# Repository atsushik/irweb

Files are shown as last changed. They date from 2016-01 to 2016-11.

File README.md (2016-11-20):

# irweb
irkitもどきを安く作るための何か

## 目的

家電を多少なりとも制御しようと思うと、既存の家電を操作するための手段が極めて限られている現実に直面する。

エアコンやテレビ、電灯などは赤外線を用いたリモコンによる操作が可能だが、WEB API的に操作できるとさらに捗りそうな気がする。

用途は例えば↓下記など。

- 寒い冬の明け方にベッドの中から他の部屋にあるエアコンの暖房をONにしたい
- 暑い夏の日に外から帰る前に室内を適温に冷やしておきたい
- 人感センサなどと組み合わせて電灯をON/OFFしたい

なお、学習リモコンは「送信できる信号は、過去に受信して記憶させたもののみ」という面で機能的に不足していると思っている。

このため、「室温が１８度になったら記憶させた温度で暖房をつける」はできるが、それ以上の細かい制御は（不可能ではないが）面倒くさいのでやらなくなる(が、多分、実用性という点ではそれで十分なのだとも思う)。

どうせなら任意の信号を出せる方が面白いと思うので簡単な変換スクリプトも作った。

## 材料
- [ESP8266なWIFIモジュール](http://akizukidenshi.com/catalog/g/gK-09758/) とARDUINOとして使うための一式
- [５ｍｍ赤外線ＬＥＤ　ＯＳＩ５ＬＡ５１１３Ａ　（１０個入）](http://akizukidenshi.com/catalog/g/gI-04311/)
- [赤外線リモコン受信モジュール　ＧＰ１ＵＸＣ４１ＱＳ](http://akizukidenshi.com/catalog/g/gI-06487/)
- [角型２色ＬＥＤ　赤・黄緑　ＧＬ８ＥＤ４８　（１０個)](http://akizukidenshi.com/catalog/g/gI-03255/)

## 配線
NODEMCUの絵を使っているけど、WROOMに適宜読み替える
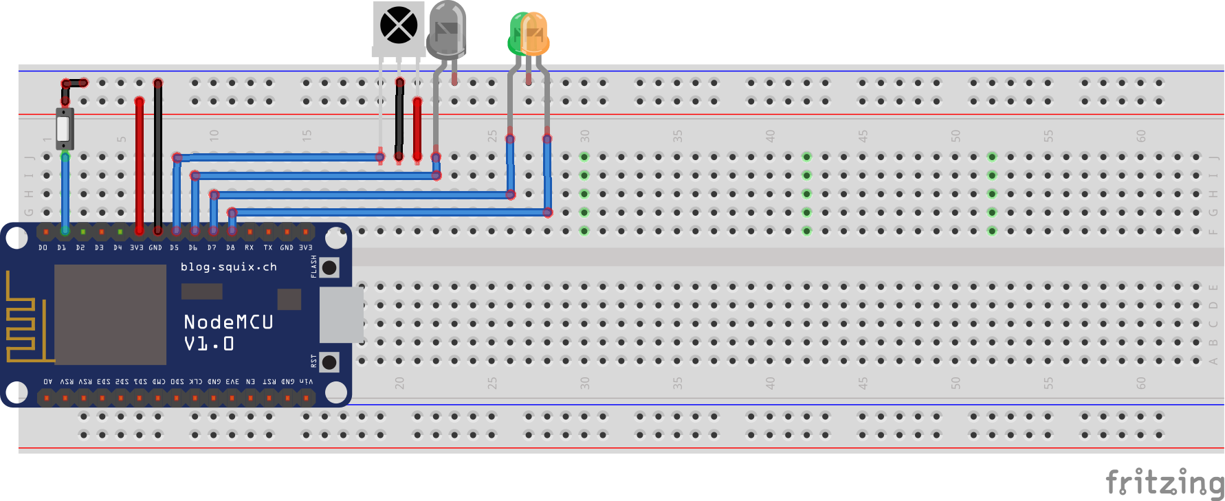
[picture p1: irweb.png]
配線図


| NODEMCU| GPIO|つなぐもの |
|:---:|:---:|:---:|
| D4 | 2 | |
| D1 | 5 | |
| D6 |  12 |５ｍｍ赤外線ＬＥＤ |
| D7 |  13 |角型２色ＬＥＤ　赤・黄緑 緑側| 
| D5 |  14 |赤外線リモコン受信モジュール |
| D8 |  15 |角型２色ＬＥＤ　赤・黄緑 赤側|
| D0 |  16 | |

## 依存しているライブラリ
- [tzapu/WiFiManager](https://github.com/tzapu/WiFiManager)
- [markszabo/IRremoteESP8266](https://github.com/markszabo/IRremoteESP8266)
- [bblanchon/ArduinoJson](https://github.com/bblanchon/ArduinoJson)

## 使い方

### 初回起動時
「irweb_c1a1」みたいなWIFI-APが出現するので、そこにつなぐ。
少し待つと「Configure WiFi」と書かれたボタンが出るので、クリックして、表示されるAP一覧から接続したいのを選びパスワードを入力する。
次回起動時からはその情報を使ってWIFIに接続するようになる。
AP情報を消すにはWIFIモジュールの起動時に GPIO 5 をGNDに繋いでおくと、保存していた情報を消す。

### esp8266の探し方
ホスト名は「irweb_」+「MACアドレスの下４文字」になっている

- osxならdns-sd コマンドで _irweb._tcp を探すとホスト名がわかる。
``` sh:find_irweb.sh
$ dns-sd -B _irweb._tcp
Browsing for _irweb._tcp
DATE: ---Sun 31 Jan 2016---
 2:21:45.561  ...STARTING...
Timestamp     A/R    Flags  if Domain               Service Type         Instance Name
 2:21:46.040  Add        2   5 local.               _irweb._tcp.         irweb_c1a1
```

- linuxならavahi-browse コマンドで _irweb._tcp を探すとホスト名がわかる。
``` sh:find_irweb.sh
$ avahi-browse _irweb._tcp
+   eth0 IPv4 irweb_c1a1                                    _irweb._tcp          local
```

### 受信
受信したリモコンの信号は下記のURLにアクセスするとjson形式で取得できる

URLのc1a1の部分は適宜変更する

http://irweb_c1a1.local/messages
``` json:aquos_power.json
{"format":"raw","freq":38,"len":99,"data":[3400,1700,450,450,450,1250,450,450,450,1250,450,450,450,1250,450,450,450,1250,450,450,450,1250,450,450,450,1250,450,1250,450,450,450,1250,450,450,450,1250,450,1250,450,1250,450,1250,450,450,450,450,450,450,450,1250,450,450,450,1250,450,450,450,450,450,1250,450,450,450,450,450,450,450,450,450,1250,450,1250,450,450,450,1250,450,450,450,450,450,450,450,1250,450,450,450,450,450,450,450,1250,450,450,450,1250,450,1250,450]}
```

### 送信
上記で取得したjsonをPOSTするとそれに応じてリモコン信号を送信する

URLのc1a1の部分は適宜変更する

``` sh:sendIrSignal.sh
curl -i "http://irweb_c1a1.local/messages" -H "X-Requested-With: curl" --data-binary @/irweb/data/sharp/ac-222fd/warm20_Louver2.json
```

### おまけ１
同梱の irweb2bin.py を使うと赤外線のON/OFFを1/0のバイナリに変換できる。
いくつかパターンを集めると、例えばエアコンの温度がどこに格納されているのかがわかるようになる。
``` sh:decodeIr.sh
$ cat /irweb/data/sharp/ac-222fd/warm20_Louver2.json | python /irweb/irweb2bin.py
AEHA	01010101010110101111001100001000110000001000100010000100000000000101000000000101000000000010011110000110
```

下記が必要
```
cpan install JSON
```

### おまけ２
同梱の bin2irweb.py を使うと1/0のバイナリを赤外線のON/OFFに変換できる。
任意の温度を設定した赤外線リモコン信号を送ることができるようになる。
``` sh:encodeIr.sh
$ echo "AEHA	01010101010110101111001100001000110000001000100010000100000000000101000000000101000000000010011110000110" | python /irweb/bin2irweb.py 
{"freq": 38, "data": [3400, 1700, 425, 425, 425, 1275, 425, 425, 425, 1275, 425, 425, 425, 1275, 425, 425, 425, 1275, 425, 425, 425, 1275, 425, 425, 425, 1275, 425, 1275, 425, 425, 425, 1275, 425, 425, 425, 1275, 425, 1275, 425, 1275, 425, 1275, 425, 425, 425, 425, 425, 1275, 425, 1275, 425, 425, 425, 425, 425, 425, 425, 425, 425, 1275, 425, 425, 425, 425, 425, 425, 425, 1275, 425, 1275, 425, 425, 425, 425, 425, 425, 425, 425, 425, 425, 425, 425, 425, 1275, 425, 425, 425, 425, 425, 425, 425, 1275, 425, 425, 425, 425, 425, 425, 425, 1275, 425, 425, 425, 425, 425, 425, 425, 425, 425, 1275, 425, 425, 425, 425, 425, 425, 425, 425, 425, 425, 425, 425, 425, 425, 425, 425, 425, 425, 425, 425, 425, 425, 425, 1275, 425, 425, 425, 1275, 425, 425, 425, 425, 425, 425, 425, 425, 425, 425, 425, 425, 425, 425, 425, 425, 425, 425, 425, 1275, 425, 425, 425, 1275, 425, 425, 425, 425, 425, 425, 425, 425, 425, 425, 425, 425, 425, 425, 425, 425, 425, 425, 425, 425, 425, 1275, 425, 425, 425, 425, 425, 1275, 425, 1275, 425, 1275, 425, 1275, 425, 425, 425, 425, 425, 425, 425, 425, 425, 1275, 425, 1275, 425, 425, 425], "len": 211, "format": "raw"}
```

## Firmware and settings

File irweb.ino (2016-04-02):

#include <ESP8266WiFi.h>          // https://github.com/esp8266/Arduino
//needed for library
#include <DNSServer.h>
#include <ESP8266WebServer.h>
#include <WiFiManager.h>          // https://github.com/tzapu/WiFiManager
//
#include <IRremoteESP8266.h>      // https://github.com/markszabo/IRremoteESP8266
//
#include <ESP8266mDNS.h>
//
//#include <ArduinoJson.h>          // https://github.com/bblanchon/ArduinoJson

// pin  0 is D3  on nodemcu
// pin  1 is D10 on nodemcu
// pin  2 is D4  on nodemcu
// pin  3 is D9  on nodemcu
// pin  4 is D2  on nodemcu
// pin  5 is D1  on nodemcu
// pin 12 is D6  on nodemcu
// pin 13 is D7  on nodemcu
// pin 14 is D5  on nodemcu
// pin 15 is D8  on nodemcu
// pin 16 is D0  on nodemcu

int RESET_AP_SETTING_PIN = 5;
int LED_RED  = 15;
int LED_GRN  = 13;
int RECV_PIN = 14;

IRrecv irrecv(RECV_PIN);
IRsend irsend(12);
decode_results  results;        // Somewhere to store the results

unsigned int irBufSize = 300;
unsigned int irBuf[300];

String jsonStr;

//String myName = "esp8266";
String myName = "irweb";

ESP8266WebServer webserver ( 80 );

byte mac[6];
char szMac[18];

void blink()
{
  for (int i = 0 ; i < 2; i++) {
    digitalWrite(LED_GRN, LOW);
    delay(60);
    digitalWrite(LED_GRN, HIGH);
    delay(60);
  }
}

void handleRoot() {
  blink();
  char temp[2048];
  int sec = millis() / 1000;
  int min = sec / 60;
  int hr = min / 60;

  snprintf ( temp, 2048,

             "<html>\
  <head>\
    <meta http-equiv='refresh' content='5'/>\
    <title>ESP8266 Demo</title>\
    <style>\
      body { background-color: #cccccc; font-family: Arial, Helvetica, Sans-Serif; Color: #000088; }\
    </style>\
  </head>\
  <body>\
    <h1>%s</h1>\
    <p>Uptime: %02d:%02d:%02d</p>\
    <p>ir-signal: %s</p>\
    <img src=\"/test.svg\" />\
    <br>\
    <pre></pre>\
  </body>\
</html>",
             myName.c_str(), hr, min % 60, sec % 60, jsonStr.c_str()
           );
  webserver.send ( 200, "text/html", temp );
}

void handleMessages() {
  Serial.print("handleMessage : begin  at ");
  Serial.println(millis());
  blink();
  if ( webserver.method() == HTTP_GET ) {
    webserver.send ( 200, "application/json", jsonStr );
    jsonStr = String("");
  }
  else if ( webserver.method() == HTTP_POST ) {
    Serial.println("POST recieved");
    for (int i = 0; i < webserver.args(); i++) {
      String s = String(webserver.argName(i));
      s += String(" -> ");
      s += String(webserver.arg(i));
      if (String(webserver.argName(i)) == String("plain")) {
        jsonStr = String(webserver.arg(i));
      }
    }
    Serial.println(jsonStr);

    unsigned int fromIdx  = jsonStr.indexOf("\"data\":", 0) + 7;
    unsigned int fromIdx2 = jsonStr.indexOf("[", fromIdx) + 1;
    unsigned int toIdx    = jsonStr.indexOf("]", fromIdx2);
    String sigStr = jsonStr.substring(fromIdx2, toIdx);
    Serial.print("data : ");
    Serial.println(sigStr);

    fromIdx = 0;
    toIdx = 0;
    unsigned int sigIdx = 0;
    while (sigStr.length() > 0) {
      toIdx = fromIdx;
      while (toIdx < sigStr.length() && sigStr.charAt(toIdx) != ',') {
        toIdx ++;
      }
      String buf = sigStr.substring(fromIdx, toIdx);
      buf.trim();
      irBuf[sigIdx] = buf.toInt();
      sigStr = sigStr.substring(toIdx+1, sigStr.length());
      sigIdx++;
    }
    irBuf[sigIdx] = sigStr.substring(fromIdx, sigStr.length()).toInt();
    irsend.sendRaw(irBuf, sigIdx, 38);
    webserver.send ( 200, "text/plain", "" );
  }
  Serial.print("handleMessage : finish at ");
  Serial.println(millis());

}

void setup() {
  // put your setup code here, to run once:
  Serial.begin(115200);
  //Serial.begin(230400);

  pinMode(RESET_AP_SETTING_PIN, INPUT_PULLUP);

  pinMode(LED_RED, OUTPUT);
  pinMode(LED_GRN, OUTPUT);

  digitalWrite(LED_RED, HIGH);
  digitalWrite(LED_GRN, HIGH);

  WiFi.macAddress(mac);
  //sprintf(szMac, "%02x:%02x:%02x:%02x:%02x:%02x", mac[0], mac[1], mac[2], mac[3], mac[4], mac[5]);
  //sprintf(szMac, "%02x%02x%02x%02x%02x%02x", mac[0], mac[1], mac[2], mac[3], mac[4], mac[5]);
  sprintf(szMac, "%02x%02x", mac[4], mac[5]);
  myName += String("_");
  myName += String(szMac);

  //WiFiManager
  //Local intialization. Once its business is done, there is no need to keep it around
  WiFiManager wifiManager;
  Serial.print("GPIO 16 is ");
  Serial.print(digitalRead(RESET_AP_SETTING_PIN));
  //reset settings
  // 電源投入時に GPIO5 がLOWならばWIFIの設定を削除する
  if ( digitalRead(RESET_AP_SETTING_PIN) == 0 ) {
    wifiManager.resetSettings();
  }

  //sets timeout until configuration portal gets turned off
  //useful to make it all retry or go to sleep
  //in seconds
  wifiManager.setTimeout(180);

  //fetches ssid and pass and tries to connect
  //if it does not connect it starts an access point with the specified name
  //here  "esp8266-" followed by MAC Address
  //and goes into a blocking loop awaiting configuration
  if (!wifiManager.autoConnect(myName.c_str())) {
    digitalWrite(LED_RED, HIGH);
    digitalWrite(LED_GRN, LOW);

    Serial.println("failed to connect and hit timeout");
    delay(3000);
    //reset and try again, or maybe put it to deep sleep
    ESP.reset();
    delay(5000);
  }

  //if you get here you have connected to the WiFi
  Serial.println("connected...yeey :)");
  digitalWrite(LED_RED, LOW);
  digitalWrite(LED_GRN, HIGH);

  irrecv.enableIRIn();  // Start the receiver
  irsend.begin();
  if ( MDNS.begin ( myName.c_str() , WiFi.localIP(), 10) ) {
    
    Serial.println ( "MDNS responder started" );
    Serial.print ( "  My name is " );
    Serial.println ( myName );
  }
  // Add service to MDNS-SD
  // ex. MDNS.addService("http", "tcp", 80);
  // OSXからは dns-sd -B _irweb._tcp として探せるようになる
  MDNS.addService("irweb", "tcp", 80);
  
  webserver.on ( "/", handleRoot );
  webserver.on ( "/messages", handleMessages );
  webserver.begin();
  Serial.println ( "HTTP server started" );
}

//+=============================================================================
// Dump out the decode_results structure.
//
String  dumpJson (decode_results *results)
{
  String jsonStr = "";
  if ((results->rawbuf[0] * USECPERTICK) < 1000) {
    return jsonStr;
  }

  jsonStr = "{\"format\":\"raw\",\"freq\":38,\"len\":";
  jsonStr += String(results->rawlen - 1);
  jsonStr += ",\"data\":[";

  // Dump data
  for (int i = 0; i < irBufSize; i++) {
    irBuf[i] = 0;
  }
  for (int i = 1;  i < results->rawlen;  i++) {
    unsigned long  x = results->rawbuf[i] * USECPERTICK;
    irBuf[i - 1] = x;
    jsonStr += String(x);
    if ( i < results->rawlen - 1 )
      jsonStr += (","); // ',' not needed on last one
  }
  jsonStr += "]}";

  //Serial.println(json);
  return jsonStr;
}

void  sendRawCode (decode_results *results)
{
  unsigned int irlen = results->rawlen - 1;
  for (int i = 1;  i < results->rawlen;  i++) {
    unsigned long  x = results->rawbuf[i] * USECPERTICK;
    irBuf[i - 1] = x;
  }
  irsend.sendRaw(irBuf, irlen, 38);
  Serial.println("");
  blink();
}

void loop() {
  webserver.handleClient();

  if (irrecv.decode(&results)) {  // Grab an IR code
    String tmpStr = dumpJson(&results);
    // if recieved IR is a remote signal, first signal will last atleast 2400 uSec
    // assuming the signal is one of NEC, AEHA, SONY
    // http://elm-chan.org/docs/ir_format.html
    if (irBuf[0] > 2000) {
      jsonStr = tmpStr;
      Serial.println(jsonStr);
      blink();
      Serial.println("-----");
    }
    irrecv.resume();              // Prepare for the next value
  }

}

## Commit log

2016-01-30 first version
    [irweb.fzz]
2016-04-02 HTTPでトップページへアクセス時に最後に受信してまだ/messagesから参照されていない赤外線信号を表示するように変更
